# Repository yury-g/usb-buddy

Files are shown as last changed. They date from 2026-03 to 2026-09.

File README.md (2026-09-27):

<div align="center">

# USB BUDDY

### A little order for your everyday cables.

**One-piece print · No assembly · Designed for support-free printing**

[**Download USB Buddy v19 →**](https://github.com/yury-g/usb-buddy/raw/refs/heads/main/usb_buddy_v19.stl) · [Edit the design](usb_buddy.scad)

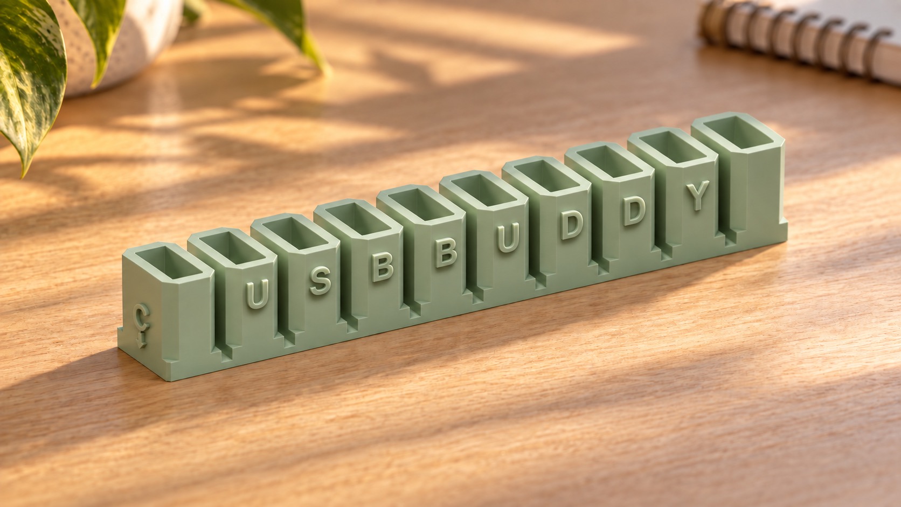
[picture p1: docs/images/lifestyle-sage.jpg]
Mint-green USB Buddy on a light bamboo surface


</div>

**One little print. Up to 20 cables organized.** Ten pods hold both ends of 10 USB-A-to-C cables, or one end each of 20 separate cables—10 USB-A and 10 USB-C. Mix the two arrangements to suit your cables.

## Two openings. One simple idea.

| USB-A goes in above | USB-C goes in below |
| :---: | :---: |
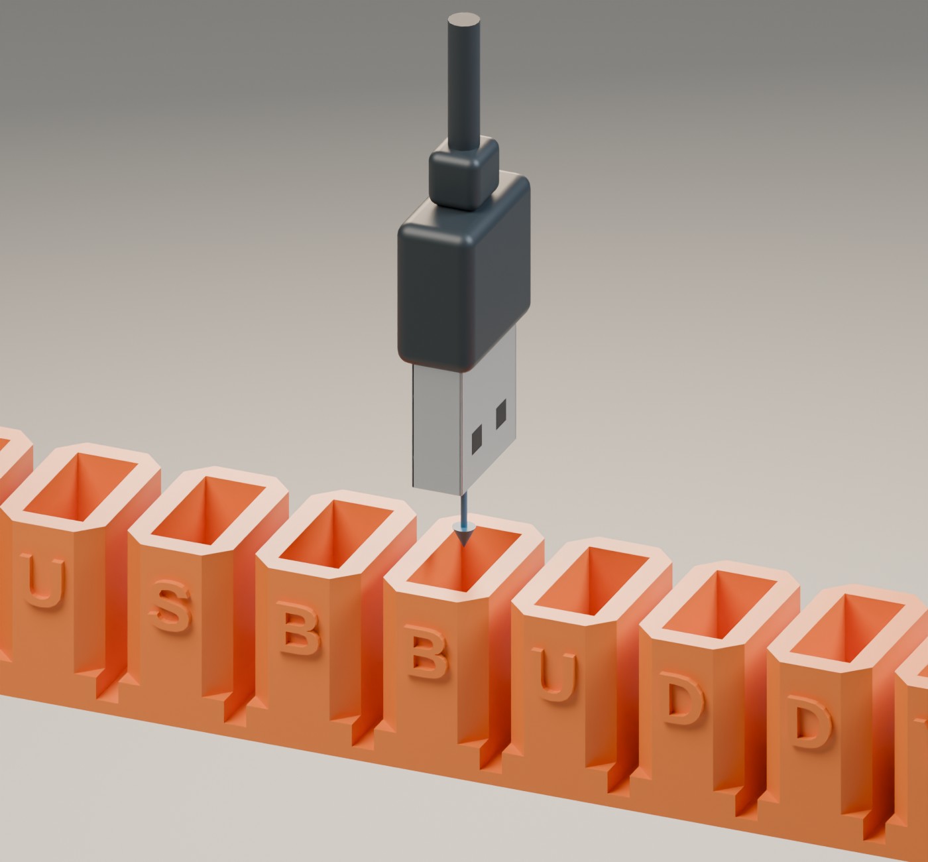
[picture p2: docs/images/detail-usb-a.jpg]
Close-up of a USB-A plug aligned above its rectangular opening, with an insertion arrow
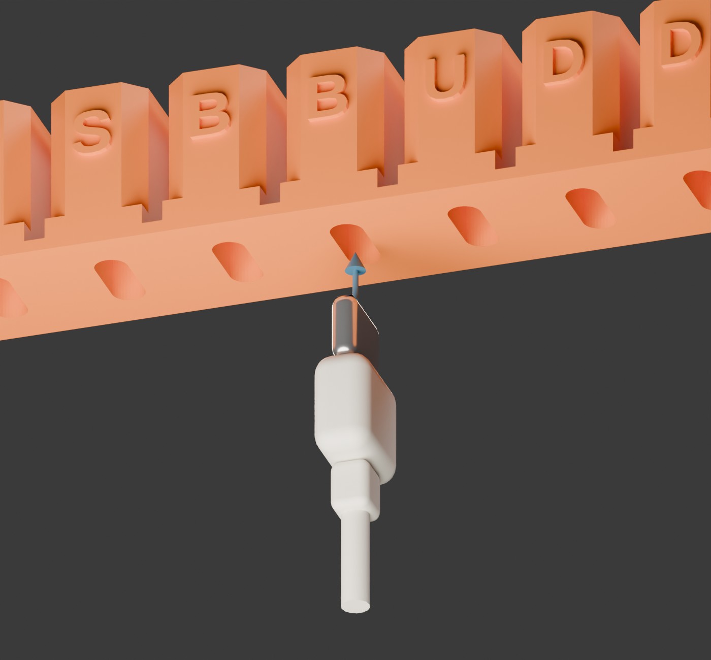
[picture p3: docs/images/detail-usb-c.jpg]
Close-up from underneath showing a USB-C plug aligned with its oval opening and an insertion arrow
|  |  |
| Park the familiar rectangular end in the top of a pod. | Park the smaller oval end underneath the same pod. |

## Your cables don't all have to match.

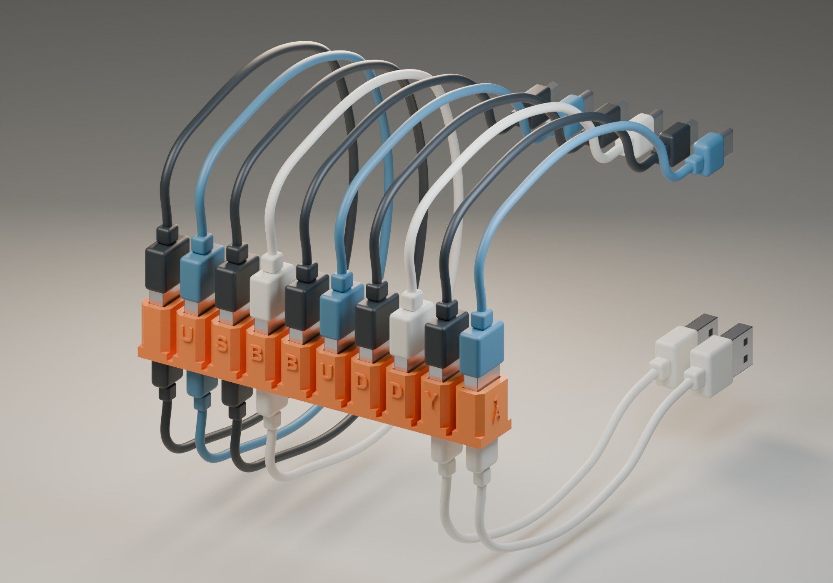
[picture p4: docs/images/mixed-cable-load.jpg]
USB Buddy holding four complete A-to-C cable loops, six additional cables with mixed USB-C and micro-USB loose ends, and two more cables parked underneath


Four cables loop back into their own pods. The rest of the strip holds a mix of everyday cables, including ones with micro-USB on the loose end. A couple of pods share space between two separate cables.

**The holder grips USB-A and USB-C ends.** A cable with micro-USB at its other end parks by its USB-A end; there's no dedicated micro-USB slot.

<sub>Connector views are CAD renders with illustrative cables. The tabletop scene is an AI-generated visualization based on the design.</sub>

## Print it. Loop it. Park it.

**[Download the current v19 STL](https://github.com/yury-g/usb-buddy/raw/refs/heads/main/usb_buddy_v19.stl)**

| Setting | Starting point |
| :--- | :--- |
| Material | PLA |
| Layer height | 0.2 mm |
| Infill | 20% or more |
| Orientation | Continuous flat strip on the bed |
| Supports | Off |
| Brim / raft | Not used in the reference slice |
| Overall size | 114.2 × 16.6 × 16.3 mm, including raised lettering |

The one-piece v19 model has been sliced with supports, brim and raft disabled. **The raised lettering still awaits a physical print check.** Connector fit depends on your cables and printer tolerances. USB Buddy is a storage holder; it does not charge or connect devices.

[Print checks and dimensions](docs/verification.md) · [Editable OpenSCAD source](usb_buddy.scad) · [Design notes](HANDOFF.md) · [Rendering files](docs/render/README.md)

Designed by [Yury Gitman](https://github.com/yury-g) · 2026

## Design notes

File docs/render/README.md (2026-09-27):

# Reproduce the product and cable views

The main images are deterministic Blender renders of `usb_buddy.stl`.
`render_cables.py` creates reusable illustrative USB-A and USB-C plug assemblies,
continuous Bezier cable curves, lighting, cameras and named scenes, then saves
`docs/models/usb-buddy-cable-scenes.blend` and JPEGs under `docs/images/`.

Requirements: OpenSCAD with the Manifold backend and Blender 5.1 or compatible.
Commands below run from the repository root; use your installed executable paths.

```sh
openscad --backend=Manifold --render -o usb_buddy.stl usb_buddy.scad
blender --background --python-exit-code 1 --python docs/render/check_model.py
blender --background --python-exit-code 1 --python docs/render/render_cables.py
```

The check fails on the original v17 STL because its instruction labels are
recessed on the front. On v19 it checks front/end embossing, a single closed component and unchanged connector
interiors against `usb_buddy_v17.stl`.

## Scene inventory

| Scene | Cables | Parked ends | Occupied pods |
| --- | ---: | ---: | ---: |
| 01-cable-loop | 1 continuous A-to-C cable | 2 | 1 |
| 10-cable-loop | 10 continuous A-to-C cables | 20 | 10 |
| 01-cable-pair | 1 A-to-C cable + 1 C-to-C cable | 2 | 1 |
| 10-cable-pair | 10 A-to-C cables + 10 C-to-C cables | 20 | 10 |

These scenes use millimeters as their modeling coordinate units. Connector shells,
overmolds and cable lengths are illustrative. The file preserves named plug parts
and editable cable curves; select a named scene in Blender to explore a layout.

`pod-cutaway` removes the front half of one actual pod to show the seated tips.
The other scenes are `product-orange`, `product-sage` and `product-graphite`.
The older `render_product.py` is a simple CAD reference-render helper.

## Insertion details and mixed load

```sh
blender --background --python-exit-code 1 --python docs/render/render_details.py
```

This adds separate USB-A and USB-C insertion close-ups and `mixed-cable-load`:
four looped A-to-C cables, three A-to-Micro-B cables, three additional A-to-C
cables, and two additional cables parked by C ends. The Micro-B ends are free;
the model does not gain a micro-USB socket. The editable scenes are in
`docs/models/usb-buddy-details.blend`.

## Archived v18 orbit and drawer

The saved orbit, drawer and evening lifestyle assets are retained v18 experiments,
not linked from the README. Regenerating them uses the current STL.

`render_orbit.py` renders the exact current STL with a looping camera orbit,
including an underside view. Its docstring contains the render and encoding
commands. Deliverables are an eight-second animated GIF, an H.264 MP4 and an
editable Blender scene. Encoding uses FFmpeg.

`render_drawer.py` builds the same oak drawer twice, with five tangled cables
on one side and five color-matched organized cables on the other. The actual
v18 model lies on its back, with the wordmark facing up and the USB-A openings
facing toward the cable coils. This is a conceptual CAD mockup, not a photograph.

## Lifestyle image

`docs/images/lifestyle-sage.jpg` was edited with the built-in image generation
tool to show the v19 raised wordmark, preserving the approved scene. The README
labels it as a visualization. `lifestyle-evening.jpg` remains an unused v18 image.
The current hero edit prompt is in [`lifestyle-v19-prompt.txt`](lifestyle-v19-prompt.txt).
Original prompts are in
[`lifestyle-prompt.txt`](lifestyle-prompt.txt) and
[`lifestyle-evening-prompt.txt`](lifestyle-evening-prompt.txt).
Earlier v17 and AI drawer experiments are not part of the published asset set.

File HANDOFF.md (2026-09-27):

# USB Buddy — current design notes

## v19 · September 27, 2026

User-approved change: move the A/C instructions off the front onto the two
outer end faces. Use the same font and size, with raised letters and arrows.
The later user-approved revision raises the front USB BUDDY wordmark as well.
The rear maker/date mark remains recessed.

- Letters: Liberation Sans Bold, 4.2 mm end labels and 4.5 mm front wordmark.
- Relief: 0.6 mm, overlapping the body by 0.05 mm for a solid union.
- Left end: C and downward arrow. Right end: A and upward arrow.
- Original body: 113 × 16 × 16.3 mm.
- Including relief: 114.2 × 16.6 × 16.3 mm.
- Pod body: 9.5 × 16 × 15.1 mm, on a 1.2 mm base.
- Gap: 2 mm. Pod pitch: 11.5 mm. Count: 10.
- Slot dimensions unchanged: A 12 × 5.5 mm; C 8.31 × 3.2 mm.

## Validation and limits

OpenSCAD Manifold export reports NoError, genus 10. Blender geometry checks
confirm raised end bounds, blank front end pods, unchanged body height/depth,
and identical interior triangles compared with the preserved v17 STL.

The old notes reported physical testing for the A and C opening dimensions.
No new physical print or cable retention test has been performed for v19.
Check raised-label readability, print quality and retention with actual cables.

The source's cuts overlap to form a continuous stepped passage. The old
description of enclosed internal air cavities is not an accurate description
of the current mesh. The older height estimate of approximately 17.6 mm is also
superseded by the measured 16.3 mm body height including base.

## Visualization models

The front page uses the updated mint-green lifestyle hero, A/C insertion close-ups,
and mixed cable load: four complete A-to-C loops, six cables parked by A (three
with Micro-B loose ends), and two additional cables parked by C. The current CAD
product/cable renders and their two Blender scene files use v19. The hero was
edited with built-in image generation to show raised letters.

The drawer, orbit and evening lifestyle assets are retained v18 experiments,
removed from the README. Their saved scenes/images are not current model previews.

The current download is `usb_buddy_v19.stl`; `usb_buddy.stl` is an identical alias.
The v18 STL preserves the former recessed front wordmark. See
[validation details](docs/verification.md) for computational checks and limits.

## Earlier records

The unmodified [v17 handoff](docs/archive/HANDOFF-v17.md) and
[v17 README](docs/archive/README-v17.md) preserve the prior session history.
Some named fit-test files in those records are not included in this repository.

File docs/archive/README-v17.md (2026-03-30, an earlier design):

# USB BUDDY

A 3D-printable combined USB-A + USB-C cable organizer strip.

10 pods on a compliant flex strip. USB-A inserts from the **top**, USB-C from the **bottom**. Prints flat, used standing upright.

## Pod cross-section

Pod cross-section

## Version timeline

Version timeline

## Design features
- 10 pods, each holding one USB-A and one USB-C cable
- 2mm chamfered vertical edges
- Front face: **USBBUDDY** (one letter per pod)
- Rear face: **yuryg 2026** (maker mark)
- End pods labeled with connector type and direction
- 1.2mm flex strip base, 2.0mm gaps between pods
- Internal air separation between USB-A and USB-C zones
- USB slots are the only airflow (no separate vents)

## Slot dimensions (locked from physical fit testing)
| Connector | Width | Height | Shape |
|---|---|---|---|
| USB-A | 12.0mm | 5.5mm | Rectangle |
| USB-C | 8.31mm | 3.2mm | Oval |

## Files
- `usb_buddy.scad` Ñ OpenSCAD source (v17)
- `usb_buddy.stl` Ñ Latest print-ready STL
- `HANDOFF.md` Ñ Full session notes for next Claude session
- `docs/` Ñ SVG diagrams

## All STLs this session

### USB-A fit test strip
| File | Description | Date |
|---|---|---|
| `usba_cable_holder_v8final.stl` | Graduated slots 13.5?11.25mm | Mar 28, 2026 15:34 |
| `usba_cable_holder_v8_2026-03-28.stl` | Locked 12.0mm Ñ production final | Mar 28, 2026 15:35 |

### USB-C fit test strips
| File | Description | Date |
|---|---|---|
| `usbc_fittest_8.65-7.30mm_v8_2026-03-28.stl` | Round 1 Ñ 0.15mm steps | Mar 28, 2026 15:40 |
| `usbc_fittest_8.55-8.10mm_v9_2026-03-28.stl` | Round 2 Ñ 0.05mm steps | Mar 28, 2026 17:20 |
| `usbc_fittest_8.55-8.10mm_v9b_2026-03-28.stl` | v9b Ñ open top restored | Mar 28, 2026 17:23 |
| `usbc_fittest_8.45-8.27mm_v9c_2026-03-28.stl` | Round 3 Ñ 0.02mm steps | Mar 28, 2026 17:25 |
| `usbc_holder_8.31mm_v10final_2026-03-28.stl` | Locked 8.31mm Ñ production final | Mar 28, 2026 19:18 |

### USB Buddy combined
| File | Description | Date |
|---|---|---|
| `usb_buddy_v13_2026-03-30.stl` | Combined pod, clean rear | Mar 30, 2026 14:45 |
| `usb_buddy_v16_2mm_chamfer_2026-03-30.stl` | 2mm chamfer added | Mar 30, 2026 14:52 |
| `usb_buddy.stl` | v17 Ñ 1.2mm strip, 2mm gaps Ñ **current** | Mar 30, 2026 14:59 |

## Print settings
- Material: PLA
- Layer height: 0.2mm
- Infill: 20%+
- Supports: None needed
- Orientation: Flat on bed

## How to render
```bash
/Applications/OpenSCAD.app/Contents/MacOS/OpenSCAD --render -o usb_buddy.stl usb_buddy.scad
```

## By
yury-g Ñ 2026

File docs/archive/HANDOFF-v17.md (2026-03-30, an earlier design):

# USB BUDDY Ñ Handoff to Next Claude Session
## Project Location
Machine: Mac Mini (mininarwhal)
Path: ~/Documents/usb-buddy/
Git: initialized, currently at v17 (main branch)
Tag: v16-chamfer-good (last fully clean version)

## What This Is
USB BUDDY is a 10-pod cable organizer strip that holds both USB-A and USB-C cables.
- USB-A male connector inserts from the TOP of each pod
- USB-C male connector inserts from the BOTTOM of each pod
- Both slots share the same pod Ñ stacked vertically
- 10 pods connected by a flexible strip (0.9mm compliant hinge base)
- Prints flat on bed, used standing upright

## Current Design State (v17)
File: usb_buddy.scad + usb_buddy.stl

### Key Dimensions
- wall = 2.0mm
- strip_t = 1.2mm (thickened from 0.9 for strength)
- gap = 2.0mm between pods (widened for flex)
- ch = 2.0mm chamfer on vertical pod edges (starts at z=ch from base)
- pod_x = 9.5mm (along strip, sized to USB-A height + walls)
- pod_y = 16.0mm (front to back)
- pod_z = ~17.6mm total height

### Z Stack (pod-local, above strip):
- 0..1.6mm       = USB-C base floor
- 1.6..4.8mm     = USB-C oval slot (8.31mm wide x 3.2mm tall)
- 4.8..6.8mm     = USB-C cap/grip (2mm)
- 6.8..7.6mm     = 0.8mm separator (structural, internal air gap cut through it)
- 7.6..13.1mm    = USB-A rect slot (12.0mm wide x 5.5mm tall)
- 13.1..15.1mm   = USB-A cap/grip (2mm)

### Slot Dimensions (locked from physical fit test prints):
- USB-A: 12.0mm wide x 5.5mm tall (rectangular)
- USB-C: 8.31mm wide x 3.2mm tall (oval Ñ hull of two circles)

### Front Face Labels (USBBUDDY):
pods: [blank, U, S, B, B, U, D, D, Y, blank]
- Pod 0 (left end): C marker + v arrow (USB-C indicator, bottom insert)
- Pod 9 (right end): A marker + ^ arrow (USB-A indicator, top insert)

### Rear Face Labels:
pods: [y, u, r, y, g, blank, 2, 0, 2, 6]
reads: yuryg 2026

## Git History Summary
- v1: initial combined A+C design
- v5: yuryg_2026 rear labels
- v10f: no vents (USB slots ARE the airflow), Genus 0 manifold Ñ GOOD BASE
- v13: BT symbol removed, pod 5 rear blank
- v14: thin separator replaces blocking shelf
- v15: 1mm chamfer added
- v16: chamfer increased to 2mm Ñ TAG: v16-chamfer-good
- v17: strip 1.2mm, gap 2.0mm, chamfer starts at z=ch (current)

## Mesh Status
- manifold: NoError (printable)
- Genus: 10 (10 enclosed internal air cavities Ñ expected, not a print issue)
- Slicers (Bambu/Prusa) handle this fine

## Known Issues / Next Steps
1. Genus 10 is benign but worth resolving cleanly Ñ the air gap internal
   cavity creates enclosed voids. Could remove the air gap cut entirely
   (sep=0.8mm is thin enough electrically) or find a way to connect it
   to an outer face without breaching walls.
2. Labels on end pods (C/v and A/^) need position review Ñ may be
   too close together vertically given the new pod_z height.
3. Consider adding a small text label on the TOP EDGE of each pod
   (reads when looking down) Ñ good for desk use.
4. USB-C test strip (separate file in ~/Documents/usb-holders/) confirmed
   8.31mm as best fit from physical testing.
5. USB-A test strip confirmed 12.0mm as best fit.
6. Both test STLs in ~/Downloads/ with dated filenames.

## How to Push to GitHub (manual step needed)
gh CLI not installed on Mini. To push:
  cd ~/Documents/usb-buddy
  git remote add origin https://github.com/yury-g/usb-buddy.git
  git push -u origin main
  git push --tags

Or install gh CLI first:
  brew install gh
  gh auth login
  gh repo create usb-buddy --public --source=. --remote=origin --push

## Related Projects
- ~/Documents/usb-holders/ Ñ USB-A and USB-C fit test strips (v8-final, v10-final)
  Both have their own git repos. USB-A locked at 12.0mm, USB-C locked at 8.31mm.
- ~/Documents/sh1106-comparison/ Ñ SH1106 OLED comparison (parked)

## SSH Access (from M4 Air or anywhere)
ssh mininarwhal (via ~/.ssh/config alias)
or: ssh mininarwhal@192.168.1.26

## OpenSCAD Render Command
/Applications/OpenSCAD.app/Contents/MacOS/OpenSCAD --render -o usb_buddy.stl usb_buddy.scad

## File Write Pattern (AppleScript Ñ ONLY method that works)
set code to "// scad content here"
set fp to open for access (POSIX file "/Users/mininarwhal/Documents/usb-buddy/usb_buddy.scad") with write permission
set eof fp to 0
write code to fp
close access fp

## Design Philosophy
- Minimal material Ñ walls only as thick as needed for grip strength
- USB slots are the only airflow (no separate vents needed)
- Flex strip connects pods Ñ prints flat, flexes at gaps when standing
- Labels serve dual purpose: product identity (front) + maker mark (rear)
- 2mm chamfer on vertical edges for feel and print quality

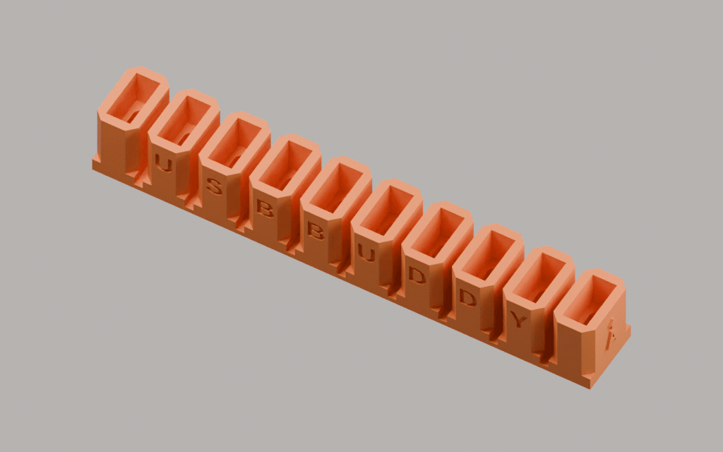
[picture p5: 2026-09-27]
docs/images/usb-buddy-orbit.gif

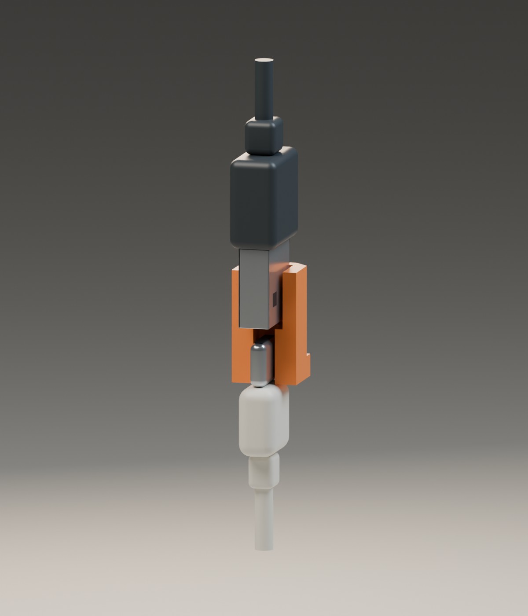
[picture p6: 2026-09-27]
docs/images/pod-cutaway.jpg

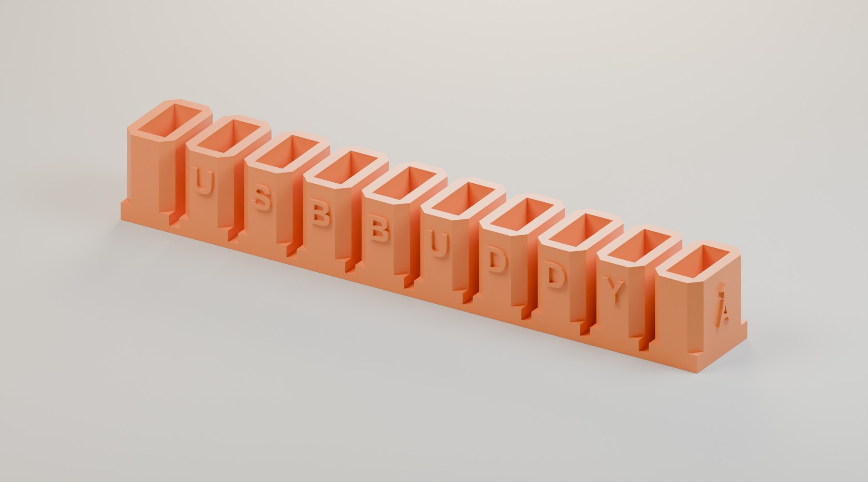
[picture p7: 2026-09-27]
docs/images/product-orange.jpg

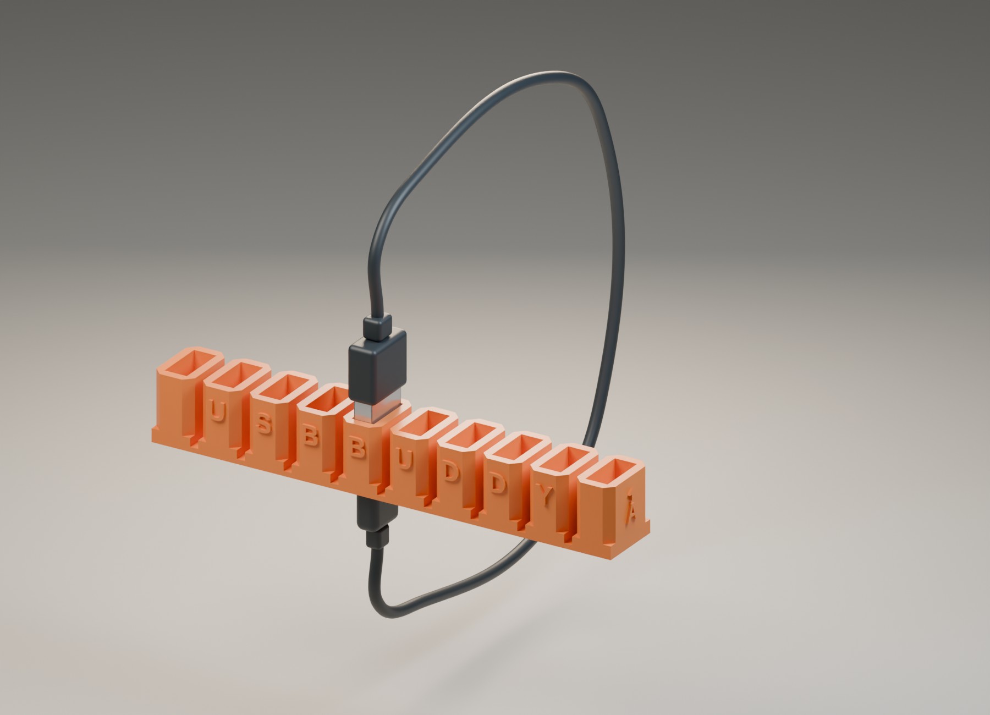
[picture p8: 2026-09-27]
docs/images/01-cable-loop.jpg

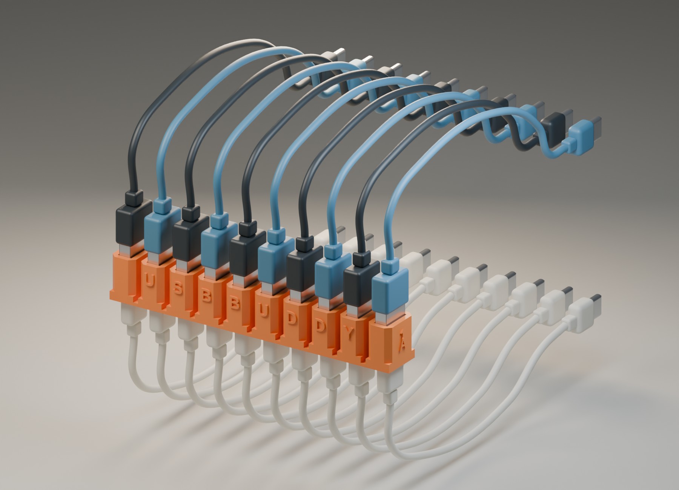
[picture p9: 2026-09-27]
docs/images/10-cable-pair.jpg

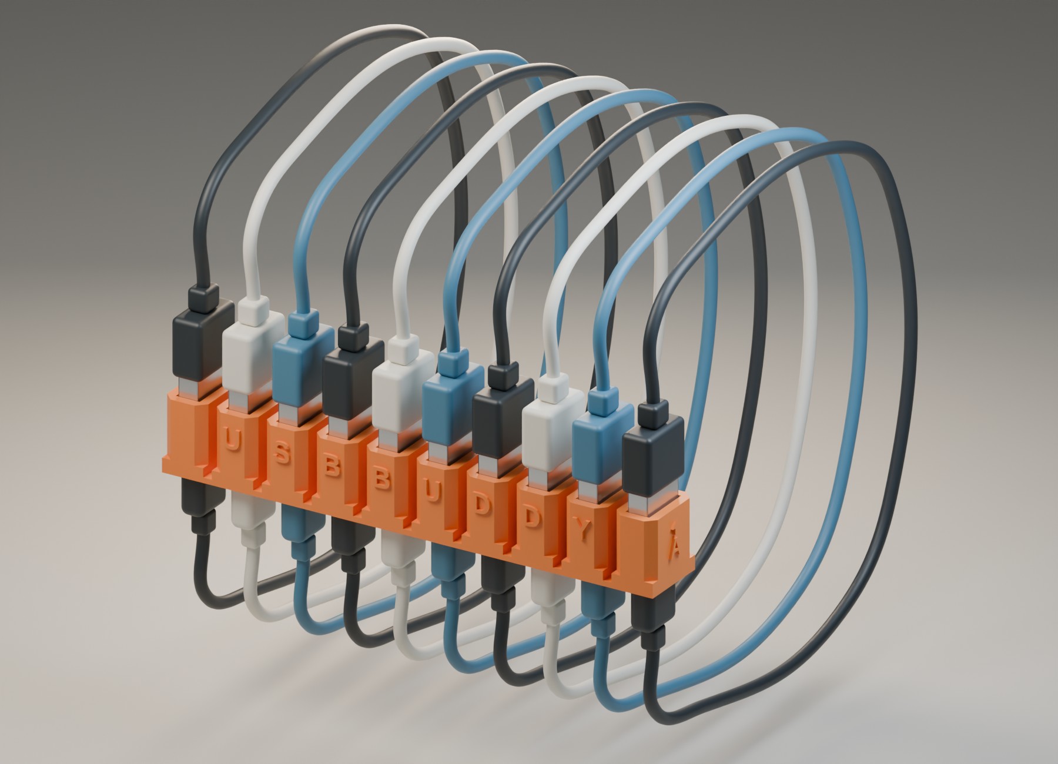
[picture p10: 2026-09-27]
docs/images/10-cable-loop.jpg

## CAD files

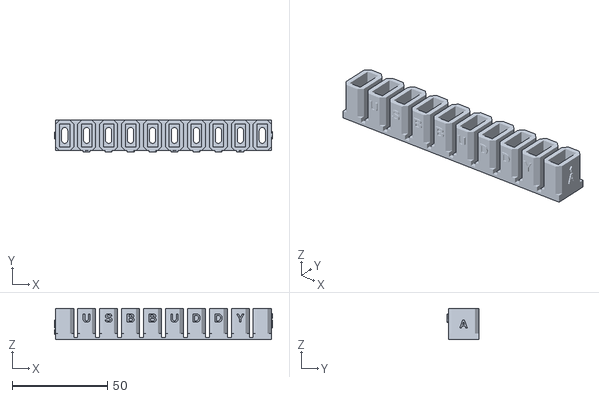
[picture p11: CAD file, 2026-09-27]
usb_buddy_v19.stl
114.2 x 16.6 x 16.3

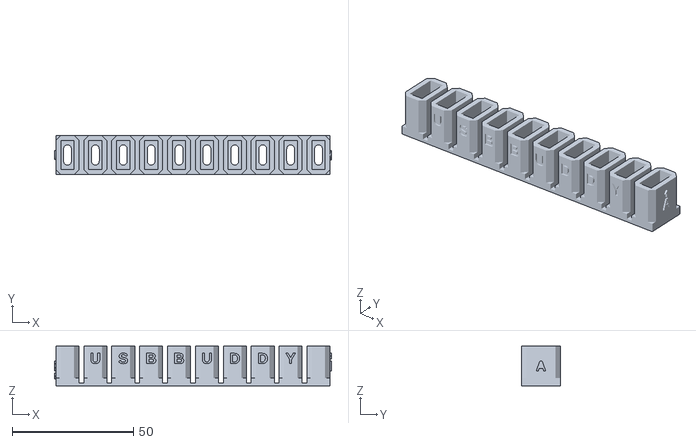
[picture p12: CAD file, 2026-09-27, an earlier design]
usb_buddy_v18.stl
114.2 x 16.0 x 16.3

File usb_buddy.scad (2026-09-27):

// USB BUDDY — v19: raised front wordmark and matched raised end labels
// strip_t=1.2mm, gap=2.0mm, 2mm chamfer on vertical edges
// Chamfer starts at z=ch from pod base so base is flush on strip

num_slots   = 10;
wall        = 2.0;
strip_t     = 1.2;
gap         = 2.0;
depth       = 0.7; // Rear maker-mark recess only
label_relief = 0.6;
ch          = 2.0;

a_w         = 12.0;
a_h         = 5.5;
a_cap       = 2.0;
c_w         = 8.31;
c_h         = 3.2;
c_cap       = 2.0;
c_floor     = 1.6;
sep         = 0.8;

pod_y       = a_w + wall * 2;
pod_x       = a_h + wall * 2;
c_top_z     = c_floor + c_h + c_cap;
a_slot_z    = c_top_z + sep;
pod_z       = a_slot_z + a_h + a_cap;
c_slot_h    = strip_t + c_floor + c_h + c_cap + 0.1;
air_slot_h  = sep + 0.1;
pitch       = pod_x + gap;
strip_len   = num_slots * pod_x + (num_slots - 1) * gap;

front_letters = ["", "U", "S", "B", "B", "U", "D", "D", "Y", ""];
rear_letters  = ["y", "u", "r", "y", "g", "", "2", "0", "2", "6"];

module oval_thru(sw,cx,cy,h) {
    r=c_h/2; s=sw-c_h;
    translate([cx,cy-s/2,0]) hull(){
        cylinder(h=h,r=r,$fn=32);
        translate([0,s,0]) cylinder(h=h,r=r,$fn=32);
    }
}

// Chamfer only on upper portion — base ch mm is square (flush on strip)
module chamfered_pod() {
    difference() {
        cube([pod_x, pod_y, pod_z]);
        // Start chamfer at z=ch, run to top
        h = pod_z - ch + 0.1;
        translate([0,    0,    ch]) linear_extrude(h) polygon([[0,0],[ch,0],[0,ch]]);
        translate([pod_x,0,    ch]) linear_extrude(h) polygon([[0,0],[-ch,0],[0,ch]]);
        translate([0,    pod_y,ch]) linear_extrude(h) polygon([[0,0],[ch,0],[0,-ch]]);
        translate([pod_x,pod_y,ch]) linear_extrude(h) polygon([[0,0],[-ch,0],[0,-ch]]);
    }
}

module raised_front(txt,sz,cx,cz) {
    translate([cx,0.05,cz]) rotate([90,0,0]) linear_extrude(label_relief+0.05)
        text(txt,size=sz,halign="center",valign="center",font="Liberation Sans:style=Bold");
}

module cut_rear(txt,sz,cx,cz) {
    translate([cx,pod_y-depth+0.01,cz]) rotate([-90,0,0]) linear_extrude(depth+0.01)
        text(txt,size=sz,halign="center",valign="center",font="Liberation Sans:style=Bold");
}

difference() {
    union() {
        cube([strip_len, pod_y, strip_t]);
        for (i=[0:num_slots-1])
            translate([i*pitch,0,strip_t]) chamfered_pod();
    }

    for (i=[0:num_slots-2])
        translate([i*pitch+pod_x,0,strip_t-0.01])
            cube([gap,pod_y,pod_z+0.1]);

    for (i=[0:num_slots-1]) {
        rl=rear_letters[i];
        translate([i*pitch,0,-0.1])
            oval_thru(c_w,pod_x/2,pod_y/2,c_slot_h);
        translate([i*pitch,0,strip_t]) {
            translate([wall,wall,c_top_z]) cube([pod_x-wall*2,pod_y-wall*2,air_slot_h]);
            translate([wall,wall,a_slot_z]) cube([a_h,a_w,a_h+a_cap+0.1]);
            if (rl!="") cut_rear(rl,4.5,pod_x/2,pod_z*0.5);
        }
    }
}

// Same font, size, relief and centered placement on both outer end faces.
// These marks add material outside the pod; connector geometry is unchanged.
// The front wordmark uses the same 0.6 mm relief as the end labels.
for (i=[0:num_slots-1])
    if (front_letters[i]!="")
        translate([i*pitch,0,strip_t])
            raised_front(front_letters[i],4.5,pod_x/2,a_slot_z+a_h*0.45);

module direction_arrow(up=true) {
    scale([1,up ? 1 : -1])
        polygon([[-0.4,-1.2],[0.4,-1.2],[0.4,0.2],
                 [1.2,0.2],[0,1.4],[-1.2,0.2],[-0.4,0.2]]);
}
module end_label(letter, right=false) {
    translate([right ? strip_len-0.05 : 0.05, pod_y/2, (strip_t+pod_z)/2])
        multmatrix(right ? [[0,0,1,0],[1,0,0,0],[0,1,0,0],[0,0,0,1]]
                          : [[0,0,-1,0],[-1,0,0,0],[0,1,0,0],[0,0,0,1]])
            linear_extrude(label_relief+0.05) {
                text(letter,size=4.2,halign="center",valign="center",
                     font="Liberation Sans:style=Bold");
                translate([0,right ? 4 : -4]) direction_arrow(right);
            }
}
end_label("C");
end_label("A",true);

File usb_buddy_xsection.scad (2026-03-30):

// USB Buddy cross-section Ñ long axis slice at Y=pod_y/2
difference() {
    import("/Users/mininarwhal/Documents/usb-buddy/usb_buddy.stl", convexity=10);
    translate([-5, -1, -5])
        cube([500, 9.0, 100]);
}

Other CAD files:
usb_buddy_v17.stl
docs/models/usb-buddy-cable-scenes.blend
docs/models/usb-buddy-details.blend
docs/models/usb-buddy-drawer.blend
docs/models/usb-buddy-orbit.blend

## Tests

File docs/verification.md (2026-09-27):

# v18 computational checks

Checked September 27, 2026. No physical print was made during this update.

## Geometry

- OpenSCAD Manifold backend: NoError, genus 10.
- One connected, closed mesh: 2,328 welded vertices, 4,692 faces.
- Zero nonmanifold edges.
- Overall bounds: 114.2 × 16 × 16.3 mm.
- Original connector interior faces match v17. The change removes the old
  front A/C instructions and adds 0.6 mm raised markings on the outer end faces.
- `usb_buddy.stl` and `usb_buddy_v18.stl` are identical copies of the current model.

## Reference slice

BambuStudio 02.00.03.54 completed the slice with exit code 0:

| Setting | Value |
| --- | --- |
| Reference printer profile | Bambu Lab A1, 0.4 mm nozzle |
| Filament | Generic PLA |
| Layer height | 0.2 mm |
| Infill | 20% |
| Orientation | Flat connecting strip on bed |
| Supports / raft / brim / skirt | Disabled |
| Layers | 81 |
| Estimated model filament | 16.63 g |
| Support metadata | support_used=false |

The reference profile is a computational check, not a requirement to own an A1.
The STL contains geometry only; it does not contain printer-specific G-code.

## Limits and messages

The slice reported no unsupported-region warning. Some paths are classified as
overhang walls, including raised-label paths, and internal paths include bridging
at z=7.2 mm. The physical appearance and retention still need a print check.

The successful slice logged seven internal `ZFiller: encounter idx from clip`
messages and a warning about the Generic PLA profile's 65°C textured-plate
temperature. It is therefore not described as a warning-free validation.

Support-free does not mean zero waste: ordinary printer priming can still consume
filament. No support structures, raft, brim, separate assembly or extra hardware
are specified for this design's reference configuration.

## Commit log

2026-03-30 v1: USB Buddy initial — combined A+C, USBBUDDY front, flip labels rear, label windows
    [usb_buddy.scad, usb_buddy.stl]
2026-03-30 v2: exact slot dims from final prints, rear face blank, front unchanged
    [usb_buddy.scad, usb_buddy.stl]
2026-03-30 v3: rear yury-g left pods, 2026 right pods, middle blank
    [usb_buddy.scad, usb_buddy.stl]
2026-03-30 v4: rear one char per pod — yury-g 2026
    [usb_buddy.scad, usb_buddy.stl]
2026-03-30 v5: rear yuryg_2026 one char per pod
    [usb_buddy.scad, usb_buddy.stl]
2026-03-30 v6: BT symbol on rear pod 5, yuryg[BT]2026
    [usb_buddy.scad, usb_buddy.stl]
2026-03-30 v7: BT Nordic B outline on rear pod 5, centered, 13mm tall
    [usb_buddy.scad, usb_buddy.stl]
2026-03-30 v8: BT symbol s=4.5 (9mm), stepped down from 13mm
    [usb_buddy.scad, usb_buddy.stl]
2026-03-30 v9: BT symbol centered, USB-C oval verified
    [usb_buddy.scad, usb_buddy.stl]
2026-03-30 v10f: no vents, USB slots are airflow, manifold Genus 0
    [usb_buddy.scad, usb_buddy.stl]
2026-03-30 v11b: 1mm internal air gap between USB-C and USB-A zones, Genus 0
    [usb_buddy.scad, usb_buddy.stl]
2026-03-30 v12: both slots open from top, side by side in Y, air gap between them
    [usb_buddy.scad, usb_buddy.stl]
2026-03-30 rollback to v10f: A plugs top, C plugs bottom, Genus 0
    [usb_buddy.scad]
2026-03-30 v13: removed BT symbol, pod 5 rear blank — yuryg blank 2026
    [usb_buddy.scad, usb_buddy.stl]
2026-03-30 v14: separator 0.8mm only, air gap cut internal, no blocking shelf, Genus 0
    [usb_buddy.scad, usb_buddy.stl, usb_buddy_xsection.scad]
2026-03-30 v15: 1mm chamfer on all 4 vertical pod edges
    [usb_buddy.scad, usb_buddy.stl]
2026-03-30 v16: chamfer increased to 2mm
    [usb_buddy.scad, usb_buddy.stl]
2026-03-30 v17: strip 1.2mm, gap 2.0mm, chamfer from z=ch up, manifold NoError
    [usb_buddy.scad, usb_buddy_v17.stl]
2026-03-30 README: full STL session log with timestamps
2026-05-10 v17: comment encoding cleanup
    [usb_buddy.scad]
2026-09-27 Present USB Buddy with cable renders and raised end labels
    [usb-buddy-cable-scenes.blend, usb_buddy.scad, usb_buddy.stl]
2026-09-27 Compare connector interiors independently of base triangulation
2026-09-27 Show USB Buddy in use with details, lifestyle scenes and 360 orbit
    [usb-buddy-details.blend, usb-buddy-drawer.blend, usb-buddy-orbit.blend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]
2026-09-27 Emboss the USB Buddy wordmark and refresh model, renders and capacity copy
    [usb-buddy-cable-scenes.blend, usb-buddy-details.blend, usb_buddy.scad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]
